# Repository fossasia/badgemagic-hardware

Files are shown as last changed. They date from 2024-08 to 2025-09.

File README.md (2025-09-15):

# Badge Magic Hardware

This repository contains the hardware design files for [Badge Magic](https://badgemagic.fossasia.org), an open-source LED badge platform that lets you create and display custom text, clipart, and animations over Bluetooth using the Badge Magic apps or Python libraries. While its latest hardware revision may not yet be mass-produced, it shares the same RISC-V chip as many other LED badges (e.g., LeSun, Victronics) but provides extra functionality, including a built-in microphone for real-time ambient sound visualization, external flash storage, and two top-mounted buttons that allow for mini-games and other interactive features. To see which functions are supported or in progress, visit the dedicated [firmware repository](https://github.com/fossasia/badgemagic-firmware). 

## PCB Layout

**Front side**

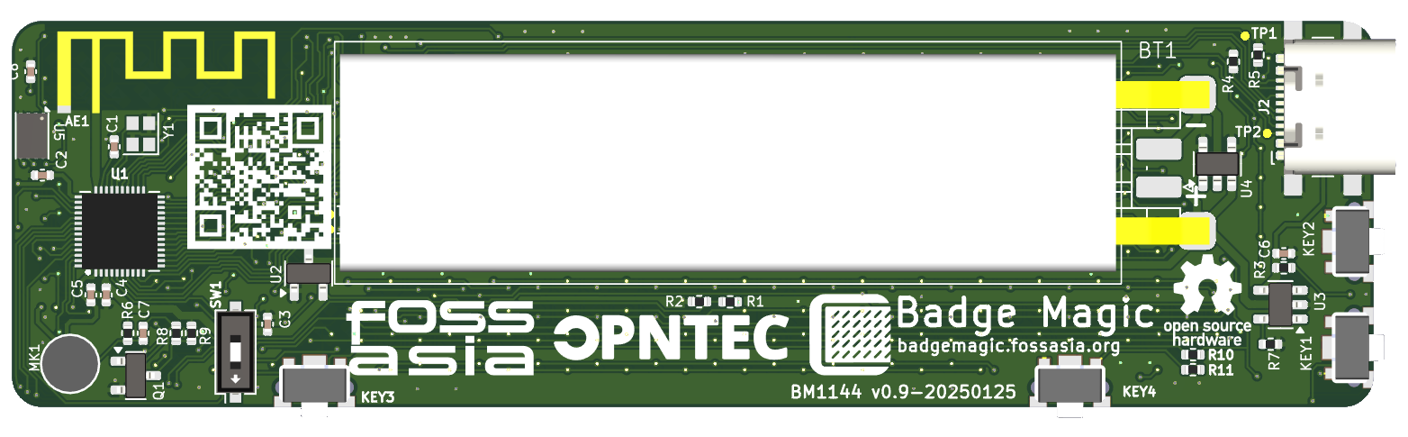
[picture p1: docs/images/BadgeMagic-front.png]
Badge Magic LED front side


**Back side**

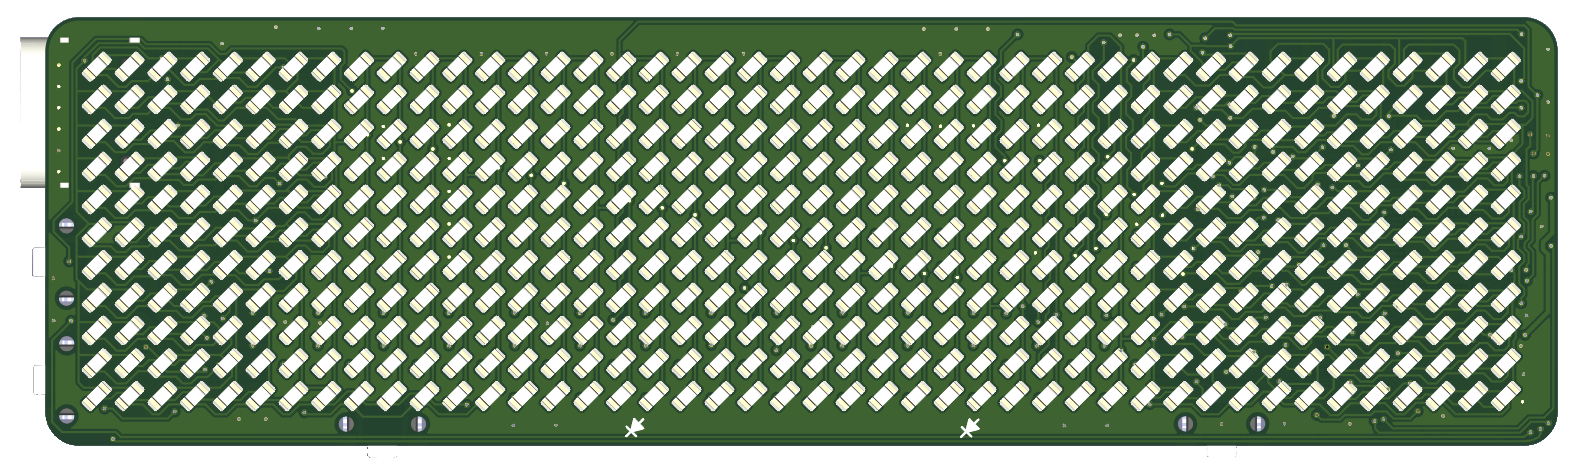
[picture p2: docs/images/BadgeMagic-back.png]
Badge Magic LED back side


## Applications and Firmware Source Repositories

The following software components are available:
* Firmware: https://github.com/fossasia/badgemagic-firmware
* Android app: https://github.com/fossasia/badgemagic-app

## Buy Device

* You can get the board at the [FOSSASIA Shop](https://fossasia.com).

## Platform

* Microcontroller Platform: [WCH QingKe RISC-V Bluetooth](https://wch-ic.com/products/productsCenter/mcuInterface?categoryId=63)
* Toolchain: [MRS_Toolchain_Linux_x64_V1.91](http://www.mounriver.com/download)
* Programming Tool: [wchisp](https://github.com/ch32-rs/wchisp)

## Parts list

- [WCH CH582M(QFN48)](https://www.wch-ic.com/download/file?id=329) Microcontroller
- [XC6206P332MR](https://www.torexsemi.com/file/xc6206/XC6206.pdf)
- [LP4054](https://xor.co.za/post/2022-11-30-hacking-smartwatch/LP4054-Lowpowersemi.pdf) 
- [DW03](https://wmsc.lcsc.com/wmsc/upload/file/pdf/v2/lcsc/2112031830_Shenzhen-Fuman-Elec-DW02R_C2927928.pdf)
- [USB-C](https://www.usb.org/sites/default/files/documents/usb_type-c.zip)
- Electret microphone
- External flash storage
- 32Mhz Crystal
- 3.7v 280mAh Li-ion battery
- LEDs, buttons, resistors, capacitors,
- and [more](docs/bill-of-materials.csv)

## Hardware Specs

- 11x44 LED Matrix display
- BLE 5.3 
- USB 1.1

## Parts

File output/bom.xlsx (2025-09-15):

Comment | Designator | Footprint | JLCPCB Part #
LED | D1,D2,D3,D4,D5,D6,D7,D8,D9,D10,D11,D12,D13,D14,D15,D16,D17,D18,D19,D20,D21,D22,D23,D24,D25,D26,D27,D28,D29,D30,D31,D32,D33,D34,D35,D36,D37,D38,D39,D40,D41,D42,D43,D44,D45,D46,D47,D48,D49,D50,D51,D52,D53,D54,D55,D56,D57,D58,D59,D60,D61,D62,D63,D64,D65,D66,D67,D68,D69,D70,D71,D72,D73,D74,D75,D76,D77,D78,D79,D80,D81,D82,D83,D84,D85,D86,D87,D88,D89,D90,D91,D92,D93,D94,D95,D96,D97,D98,D99,D100 | LED_0603 | C965799
LED | D101,D102,D103,D104,D105,D106,D107,D108,D109,D110,D111,D112,D113,D114,D115,D116,D117,D118,D119,D120,D121,D122,D123,D124,D125,D126,D127,D128,D129,D130,D131,D132,D133,D134,D135,D136,D137,D138,D139,D140,D141,D142,D143,D144,D145,D146,D147,D148,D149,D150,D151,D152,D153,D154,D155,D156,D157,D158,D159,D160,D161,D162,D163,D164,D165,D166,D167,D168,D169,D170,D171,D172,D173,D174,D175,D176,D177,D178,D179,D180,D181,D182,D183,D184,D185,D186,D187,D188,D189,D190,D191,D192,D193,D194,D195,D196,D197,D198,D199,D200 | LED_0603 | C965799
LED | D201,D202,D203,D204,D205,D206,D207,D208,D209,D210,D211,D212,D213,D214,D215,D216,D217,D218,D219,D220,D221,D222,D223,D224,D225,D226,D227,D228,D229,D230,D231,D232,D233,D234,D235,D236,D237,D238,D239,D240,D241,D242,D243,D244,D245,D246,D247,D248,D249,D250,D251,D252,D253,D254,D255,D256,D257,D258,D259,D260,D261,D262,D263,D264,D265,D266,D267,D268,D269,D270,D271,D272,D273,D274,D275,D276,D277,D278,D279,D280,D281,D282,D283,D284,D285,D286,D287,D288,D289,D290,D291,D292,D293,D294,D295,D296,D297,D298,D299,D300 | LED_0603 | C965799
LED | D301,D302,D303,D304,D305,D306,D307,D308,D309,D310,D311,D312,D313,D314,D315,D316,D317,D318,D319,D320,D321,D322,D323,D324,D325,D326,D327,D328,D329,D330,D331,D332,D333,D334,D335,D336,D337,D338,D339,D340,D341,D342,D343,D344,D345,D346,D347,D348,D349,D350,D351,D352,D353,D354,D355,D356,D357,D358,D359,D360,D361,D362,D363,D364,D365,D366,D367,D368,D369,D370,D371,D372,D373,D374,D375,D376,D377,D378,D379,D380,D381,D382,D383,D384,D385,D386,D387,D388,D389,D390,D391,D392,D393,D394,D395,D396,D397,D398,D399,D400 | LED_0603 | C965799
LED | D401,D402,D403,D404,D405,D406,D407,D408,D409,D410,D411,D412,D413,D414,D415,D416,D417,D418,D419,D420,D421,D422,D423,D424,D425,D426,D427,D428,D429,D430,D431,D432,D433,D434,D435,D436,D437,D438,D439,D440,D441,D442,D443,D444,D445,D446,D447,D448,D449,D450,D451,D452,D453,D454,D455,D456,D457,D458,D459,D460,D461,D462,D463,D464,D465,D466,D467,D468,D469,D470,D471,D472,D473,D474,D475,D476,D477,D478,D479,D480,D481,D482,D483,D484 | LED_0603 | C965799
Conn_01x02 | J1 | JST_1x02_P2.50mm_SMD_Horizontal | C7429680
CH582M | U1 | CH582-QFN-48-1EP_5x5mm_P0.35mm_EP3.7x3.7mm | C2920766
MMBT3904 | Q1 | SOT-23 | C20526
3k92 | R7 | 0402 | C137988
47k | R8 | 0402 | C25792
button | KEY1,KEY2,KEY3,KEY4 | 1TS003A-1800-3500A-CT | C255805
DW03 | U4 | SOT-23-5 | C5122490
USB_C_Receptacle_USB2.0_16P | J2 | USB_C_Receptacle_GCT_USB4110 | C963216
MIC-4013-G-G00 | MK1 | microphone | C42371093
NORFlash | U5 | USON-8_2x3 | C7462744
2.2uF | C1,C2,C3,C4,C5,C6,C7,C8 | 0402 | C12530
100k | R2 | 0402 | C60491
4.7k | R6,R9 | 0402 | C25940
XC6206P362MR | U2 | SOT-23-3 | C351446
LP4054 | U3 | SOT-23-5 | C517187
32MHz | Y1 | Crystal_SMD_2016-4Pin_2.0x1.6mm | C2901738
30K | R3 | 0402 | C25776
5.1k | R4,R5 | 0402 | C25941
1k | R10,R11 | 0402 | C2906899
182k | R1 | 0402 | C5159679
SW_DIP_x01 | SW1 | SW_DIP_SPSTx01_Slide_Copal_CHS-01TA_W5.08mm_P1.27mm_Jpin | C2921603

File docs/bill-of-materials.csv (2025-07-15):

Reference | Value | Datasheet | Footprint | Qty
BT1 | 3.7v 280mAh | ~ | BadgeMagic:Battery cell | 1
C1,C2,C3,C4,C5,C6,C7,C8 | 2.2uF | ~ | Capacitor_SMD:C_0402_1005Metric | 8
D1,D2,D3,D4,D5,D6,D7,D8,D9,D10,D11,D12,D13,D14,D15,D16,D17,D18,D19,D20,D21,D22,D23,D24,D25,D26,D27,D28,D29,D30,D31,D32,D33,D34,D35,D36,D37,D38,D39,D40,D41,D42,D43,D44,D45,D46,D47,D48,D49,D50,D51,D52,D53,D54,D55,D56,D57,D58,D59,D60,D61,D62,D63,D64,D65,D66,D67,D68,D69,D70,D71,D72,D73,D74,D75,D76,D77,D78,D79,D80,D81,D82,D83,D84,D85,D86,D87,D88,D89,D90,D91,D92,D93,D94,D95,D96,D97,D98,D99,D100,D101,D102,D103,D104,D105,D106,D107,D108,D109,D110,D111,D112,D113,D114,D115,D116,D117,D118,D119,D120,D121,D122,D123,D124,D125,D126,D127,D128,D129,D130,D131,D132,D133,D134,D135,D136,D137,D138,D139,D140,D141,D142,D143,D144,D145,D146,D147,D148,D149,D150,D151,D152,D153,D154,D155,D156,D157,D158,D159,D160,D161,D162,D163,D164,D165,D166,D167,D168,D169,D170,D171,D172,D173,D174,D175,D176,D177,D178,D179,D180,D181,D182,D183,D184,D185,D186,D187,D188,D189,D190,D191,D192,D193,D194,D195,D196,D197,D198,D199,D200,D201,D202,D203,D204,D205,D206,D207,D208,D209,D210,D211,D212,D213,D214,D215,D216,D217,D218,D219,D220,D221,D222,D223,D224,D225,D226,D227,D228,D229,D230,D231,D232,D233,D234,D235,D236,D237,D238,D239,D240,D241,D242,D243,D244,D245,D246,D247,D248,D249,D250,D251,D252,D253,D254,D255,D256,D257,D258,D259,D260,D261,D262,D263,D264,D265,D266,D267,D268,D269,D270,D271,D272,D273,D274,D275,D276,D277,D278,D279,D280,D281,D282,D283,D284,D285,D286,D287,D288,D289,D290,D291,D292,D293,D294,D295,D296,D297,D298,D299,D300,D301,D302,D303,D304,D305,D306,D307,D308,D309,D310,D311,D312,D313,D314,D315,D316,D317,D318,D319,D320,D321,D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 | LED | ~ | BadgeMagic:LED_0603 | 484
J1 | Conn_01x02 | ~ | BadgeMagic:JST_1x02_P2.50mm_SMD_Horizontal | 1
J2 | USB_C_Receptacle_USB2.0_16P | https://www.usb.org/sites/default/files/documents/usb_type-c.zip | BadgeMagic:USB_C_Receptacle_GCT_USB4110 | 1
KEY1,KEY2,KEY3,KEY4 | button | https://www.lcsc.com/product-detail/Tactile-Switches_HYP-Hongyuan-Precision-1TS003A-1800-3500A-CT_C255806.html | BadgeMagic:1TS003A-1800-3500A-CT | 4
MK1 | SAMZO MIC-4013-G-G00 | https://lcsc.com/datasheet/lcsc_datasheet_2410281656_SAMZO-MIC-4013-G-G00_C42371093.pdf | BadgeMagic:microphone | 1
Q1 | MMBT3904 | https://www.onsemi.com/pdf/datasheet/pzt3904-d.pdf | Package_TO_SOT_SMD:SOT-23 | 1
R1 | 182k | ~ | Resistor_SMD:R_0402_1005Metric | 1
R2 | 100k | ~ | Resistor_SMD:R_0402_1005Metric | 1
R3 | 30K | ~ | Resistor_SMD:R_0402_1005Metric | 1
R4,R5 | 5.1k | ~ | Resistor_SMD:R_0402_1005Metric | 2
R6,R9 | 4.7k | ~ | Resistor_SMD:R_0402_1005Metric | 2
R7 | 3k92 | ~ | Resistor_SMD:R_0402_1005Metric | 1
R8 | 47k | ~ | Resistor_SMD:R_0402_1005Metric | 1
R10,R11 | 1k | ~ | Resistor_SMD:R_0402_1005Metric | 2
SW1 | SW_DIP_x01 | ~ | Button_Switch_SMD:SW_DIP_SPSTx01_Slide_Copal_CHS-01A_W5.08mm_P1.27mm_JPin | 1
U1 | CH582M | https://github.com/openwch/ch583/tree/main/Datasheet | BadgeMagic:CH582-QFN-48-1EP_5x5mm_P0.35mm_EP3.7x3.7mm | 1
U2 | XC6206P362MR | https://www.torexsemi.com/file/xc6206/XC6206.pdf | Package_TO_SOT_SMD:SOT-23-3 | 1
U3 | LP4054 | https://xor.co.za/post/2022-11-30-hacking-smartwatch/LP4054-Lowpowersemi.pdf | Package_TO_SOT_SMD:TSOT-23-5 | 1
U4 | DW03 | https://wmsc.lcsc.com/wmsc/upload/file/pdf/v2/lcsc/2112031830_Shenzhen-Fuman-Elec-DW02R_C2927928.pdf | Package_TO_SOT_SMD:SOT-23-5 | 1
U5 | NOR Flash | ~ | BadgeMagic:USON-8_2x3 | 1
Y1 | 32 MHz | ~ | Crystal:Crystal_SMD_2016-4Pin_2.0x1.6mm | 1

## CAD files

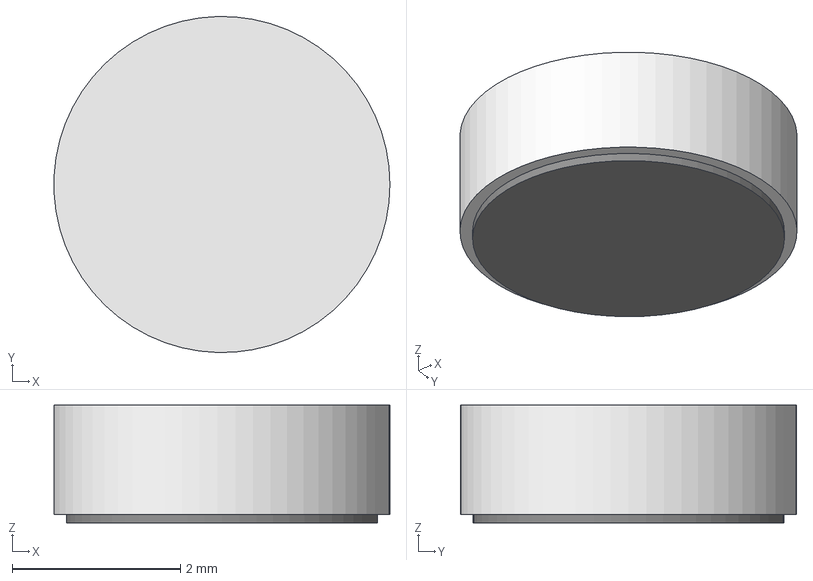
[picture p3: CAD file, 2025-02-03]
schematics/3dmodels/microphone.step
4.00 x 4.00 x 1.40 mm

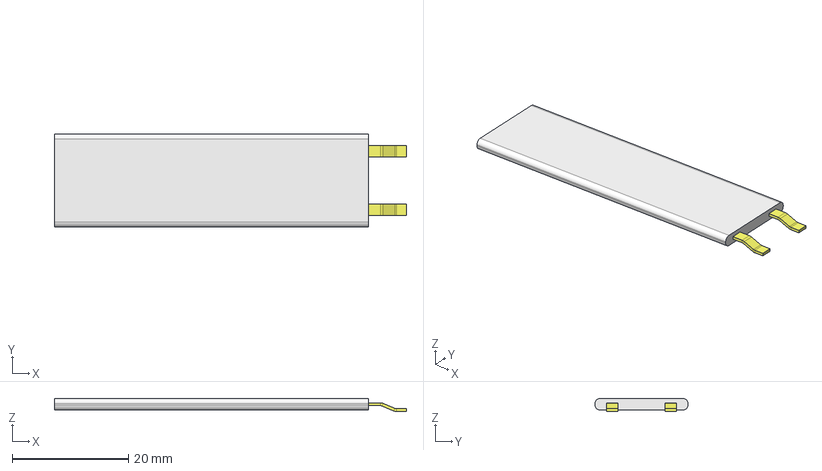
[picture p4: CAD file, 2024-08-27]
schematics/3dmodels/batt.step
60.5 x 16.0 x 2.25 mm
electro1
electro2

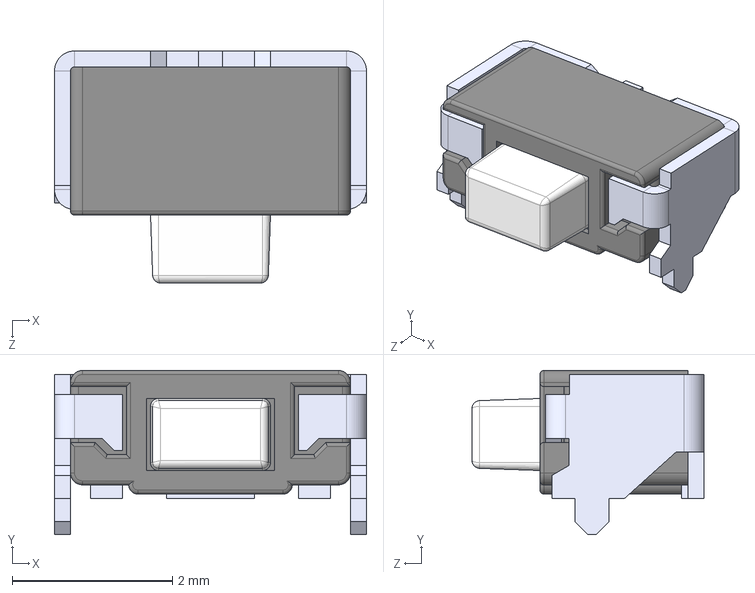
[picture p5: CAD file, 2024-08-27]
schematics/3dmodels/1TS003A-1800-3500A-CT.step
3.90 x 2.05 x 2.90 mm

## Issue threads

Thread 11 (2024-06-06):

Mismatch PCB / Schematic

simon-budig, 2024-06-06:
When looking at the PCB of my (violet) badge I've noticed that there is a mismatch between the PCB and the kicad schematics.

For me the silkscreen on the PCB shows the markings "KEY1" "IC1" and "C3". It seems that they refer to the three parts (button, voltage regulator, capacitor) to the left of them.

The schematics refer to the voltage regulator as "U2", I suspect this could be changed to "IC1" to match up the labels.

Also, the voltage regulator on my board is marked "665k", which refers to the 3.6V-version of the XC6206 (which also matches the measured voltage on my badge). If that part is the same for the other colors of the badge (not sure about that, different color LEDs might need slightly different voltages) the part number in the schematics could be adjusted to "XC6206P362MR".

kienvo, 2024-06-09:
Sorry for being late. I forgot to turn on notification for this repo.

For the IC ref, not just IC1 was mismatched but all four ICs. Two of them were missed ref. The two others were "IC1" and "U1", but they don't match up. IMO, ICs shouldn't have two different ref notations in the same schematic, so they were intentionally annotated from left to right. We could drop a short note near the regulator symbol to indicate this is "IC1" on the original PCB, and so the charger.

About the regulator, I've just checked on red, yellow, and green; they are the same "665k". It was my mistake, didn't notice the part number while pulling it out from built-in symbol.

Closed 2024-08-11.

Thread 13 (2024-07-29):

Design a new board

kienvo, 2024-07-29:
For now, we have just a schematic for firmware reference. We will need a new PCB with more features added, easier debugging, and better design.

Closed 2024-08-27.

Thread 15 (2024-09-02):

Unconnected LEDs

kienvo, 2024-09-02:
Half of the LEDs (pins in the green rectangle below) are mistakenly left unconnected in the schematic.

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

Closed 2024-09-08.

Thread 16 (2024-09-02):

PCB dimensions are incompatible with other versions

kienvo, 2024-09-02:
The current board is slightly bigger than the other versions, making it difficult to interchange with the same casing.

Closed 2024-09-08.

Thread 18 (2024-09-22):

Add a mechanical switch to disable microphone - most hackers hate microphones without hardware switches

froscon2024, 2024-09-22:
The badge is been sold often at hackerspace-minded people. The upcomming USB-C version have a microphone build in: https://github.com/fossasia/badgemagic-hardware/pull/14#issuecomment-2297284782
Could you please add a hardware switch that can turn on and off the microphone? There would be for sure many hackers that would not like to have a microphone the can not turn off.

I would let a picture of the PinePhone (Pro) with its dip-switches that can fully disable microphone here for inspiration.
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

Closed 2024-11-03.

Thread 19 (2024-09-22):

Make the battery detachable without the need of soldering - have to be detached to update firmware at the moment

froscon2024, 2024-09-22:
At the moment the battery have to be detached to update firmware.
https://github.com/fossasia/badgemagic-firmware/issues/38
Having to apply high temperature at the contacts of a lithium battery to install FOSS-firmware is really not great. Please make the battery detachable with a typical connector. This would also make it more user friendly to replace or upgrade the battery. Soldered in batteries are in general not great and if the badge would at some time be reviewed by ifixit it would get negative points for the soldered in battery. There are a ton of cheap, simple and flat connectors you can use instead.

kienvo, 2024-09-23:
Not sure how ifixit will rate a 2-pos DIP switch for both this and #18 :D

froscon2024, 2024-09-25:
I was more thinking of a connector for the battery. Not a DIP switch. Ifixit love of course not soldered in batteries. You can disconnect the battery thanks to the connector to flash but also to hack around with the badge. When you for example need for a special use case where the badge should run a week untouched, then disconnect the internal battery, leave the back off and connect with the same connector type some different battery. For example a 5000mAh 21700 battery cell.
Typical connectors hardware hackers and hackerspaces have around are the ones from the CR2032 batteries used in thinkpads. The connector is small, should fit inside the badge without problems and hardware hackers can already have some of them around.
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

Closed 2024-11-03.

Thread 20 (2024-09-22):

CH583, CH582M or CH582 build in? lsusb reports CH583

froscon2024, 2024-09-22:
What chipset is build into the hardware revision @mariobehling brought to froscon 2024? In lsusb/dmesg it reports with the preinstalled firmware to be a CH583.
The parts list is telling to be a CH582M https://github.com/fossasia/badgemagic-hardware?tab=readme-ov-file#parts-list
The firmware page is telling to be a CH582 https://github.com/fossasia/badgemagic-firmware?tab=readme-ov-file#chipset

kienvo, 2024-09-23:
CH583 is CH583M for short =], the same for CH582. Comparison table from the datasheet:
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

CH582 and CH583 are almost identical. The difference is the CH583 has an additional SPI and 1.7v min. supply voltage. In most cases, they can be interchangeable.

froscon2024, 2024-09-23:
Thanks for the information.
What does your preinstalled OEM closed source firmware say about the build in chipset in lsusb?

kienvo, 2024-09-23:
Both my USB-C version and Micro-USB version, lsusb said 'CH583', but the chip is CH582.

froscon2024, 2024-09-25:
I flashed some hours ago on all badges i have the foss firmware. I checked on the chip and it was always WCH labeled CH582M.

Closed 2024-09-25.

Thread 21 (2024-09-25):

Do not use the suppier of the yellow badges any more - bad build quality, a not working LED and missing part on PCB

froscon2024, 2024-09-25:
I have badges with different colors from Froscon2024. The yellow one looks really bad. One of the LED's simply just do not work. I opened it to flash the new FOSS firmware and compared to other ones its really bad overall. Even the used solderpaste they used to solder on the battery is the really worse one. The one that leave behind not a shiny surface but a milky mess. Even after i heated it up twice (disconnect and connect of battery to flash firmware) the solder stayed like that. I know this type of solder and its always used on really, really crappy products.
The PCB also miss a part that is not missing on the other ones. Its the SMD part directly next to "R3" that is on the bottom of the PCB next to the battery.
And the worst part is one of the yellow LED's is not working in the middle of the badge. It does not matter if closed source firmware or the new released opensource one. It always stay dark, break the letters i try to write and just look bad.
The PCB number of the yellow badge is B1144_220515. Its also missing the production date the other have on the top right next to the PCB number.

mariobehling, 2025-01-09:
Hi @froscon2024 we are still looking at options for future production batches. Even though it is already some time ago, could you take maybe a picture of the issue with the yellow LED?

froscon2024, 2025-08-25:
I think this is solved now. The badge with this production issues have been shown and discussed in person to @mariobehling

Closed 2025-08-25.

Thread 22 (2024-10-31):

Case compatibility

kienvo, 2024-10-31:
The current PCB has battery position that won't fit into the case.

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

Closed 2024-10-31.

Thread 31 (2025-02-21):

Correcting the debug port

kienvo, 2025-02-21:
I was experimenting with the debug port and confirmed that the debug port is working on PB14/PB15, not PB16/PB17 like the OEM boards.

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

Closed 2025-04-07.

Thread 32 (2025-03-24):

Context of the board with other fossasia badges

chrysn, 2025-03-24:
Great to see a Open Hardware badge being developed in this form!

The current README is a bit confusing when coming to this as a user of existing badges that were resold from [LeSun Electronics B1144](https://lesun-led.en.alibaba.com/) -- it easily becomes unclear which hardware one has at hand, and which firmware might work for it.

Could you add some information to the README on how this relates to other boards, and which level of compatibility does it aim for (apparently it aims for display compatibliity with the 11x44 LEDs, but is pin compatibility a goal too?), and what its relation their relation is?

mariobehling, 2025-03-25:
Ok, thanks for question! I think this question is even more relevant for the firmware repo. So, I am moving it there.

To clarify in this repo regarding the hardware, I added the following text into the readme intro already:

While its latest hardware revision may not yet be mass-produced, it shares the same RISC-V chip as many other LED badges (e.g., LeSun, Victronics) but provides extra functionality, including a built-in microphone for real-time ambient sound visualization, external flash storage, and two top-mounted buttons that allow for mini-games and other interactive features. To see which functions are supported or in progress, visit the dedicated [firmware repository](https://github.com/fossasia/badgemagic-firmware).

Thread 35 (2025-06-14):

Badge case doesn't fit after attaching battery connector

hpdang, 2025-06-14:
Once the battery connector (ZX-XH2.54-2PLT) is attached to the LED badge, the existing case no longer fits properly.

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

froscon2024, 2025-08-30:
@mariobehling @hpdang @kienvo
The connector that got installed on there is a complete misunderstanding and that is why it does not fit like written in this issue. Also the huge connector is missing the essential pads left and right for stability on the PCB. The first time the user would have connected or disconnected the battery, the pads would have been ripped off the PCB.

The history of the battery connector for the badge is here: https://github.com/fossasia/badgemagic-hardware/issues/19

I wrote there:
> Typical connectors hardware hackers and hackerspaces have around are the ones from the CR2032 batteries used in thinkpads. The connector is small, should fit inside the badge without problems and hardware hackers can already have some of them around.

Short after the text i wrote it got closed as completed and i expected to have helped with the hardware design to solve the battery disconnect and reconnect issue for flashing and crashed badges. Also for making it possible to replace the battery for a bigger one on the fly, or just easy replace a battery that is worn out after for example 10 years.
A soldered in battery is also bad for repair score at https://www.ifixit.com/ and just bad in general. That is why every good device these days is using a connector to connect a battery and not solder.

When i was sitting at froscon2025 next to @mariobehling holding the prototype PCB in my hand i was fully surprised to see a completely different connector on there that obviously does not fit like shown in the first post here.
I opened yewtu.be while sitting next to @mariobehling and showred one of the many videos you can find that show the connector i described. Some example videos:
https://yewtu.be/watch?v=CJtH5S7RURo&t=3m11s
https://yewtu.be/watch?v=VDBTvgQPmls&t=2m28s
https://yewtu.be/watch?v=mV4HNVSFeqg&t=3m15s

The connector is really common. For example also used on this LoRA board for battery connection: https://lilygo.cc/products/lora3

Its the classical connector hardware hackers have around from old/broken notebooks for many, many years.

I soldered out one of those from a broken notebook to completely make sure i do not get misunderstood again:

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

I was really not expecting to be misunderstood that bad. So let me write more about how to design that part:
I know that having more layers is costly. That is where the connector also benefits. Because the metal left and right next to the connector does not have any electrical connection (like for example the housing of a usb-c SMD connector).
That is why you could for example just leave two holes in the coating and then the connector would be soldered its left and right stability marts on to two led pins. Yes, the voltage from those two LED pins would also be on the left and right side of the battery connector, but that should not matter, because from the electrical point of view those are isolated.
You can also move the connector around in the PCB design. The connector does not have to be in the middle where the battery was soldered before. Because thanks to connecting the battery with a short wire, the placing of the connector is flexible now.
But do not forget the pads left and right that protects the connector from getting ripped from the PCB when connecting and disconnecting the battery. Those are the pads that hold the battery connector in place. Not the two electric relevant pads on the back that connect the battery.
I am telling this especially because those two pads left and right next to the connector was also required for the huge wrong connector but is also missing on there.

From DIY-perspective the correct connector you can see on the last picture have been glued down to not pull/push on the pins on the back and because the essential pads was missing.
You can see in the picture where both, the wrong huge and the correct small are upside down next to each other with white background. Both connectors have those isolated stability pads left and right next to them.

In the last picture you can see that the correct connector is smaller then the USB-C connector and would fit without any issues in the case.

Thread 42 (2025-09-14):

Discussion: Update to the newer CH585M/585M, also now more options to reduce to smaller chip size

froscon2024, 2025-09-14:
There is the now the new chipset released by WCH. I checked the QFN48 version and its pin compatible to my understanding with the CH582M QFN48 that is used now.

Datasheet of CH583/582: https://www.wch-ic.com/download/file?id=329
Datasheet of CH585/584: https://www.wch-ic.com/download/file?id=402

Compare: https://wch-ic.com/products/productsCenter/mcuInterface?categoryId=63

The CH585 have higher speed then the current CH582. This should have general benefits for example when developing games. Also things like sound processing from the microphone and so on could benefit from the higher clock speed.
The USB speed have been updated. The size of data transferred over USB is not that relevant currently, but maybe it would get later with the flexibility the badgemagic hardware gives.

If chip size matter, there are more options now. Before there was just the the CH582F(QFN28) that was smaller then the QFN48. Now there are many more options. But of course you loose functionality and have PCB design work when you reduce the pin count. So keeping the biggest size (QFN48) would be of course at best when the size of the WCH chip was not a problem.

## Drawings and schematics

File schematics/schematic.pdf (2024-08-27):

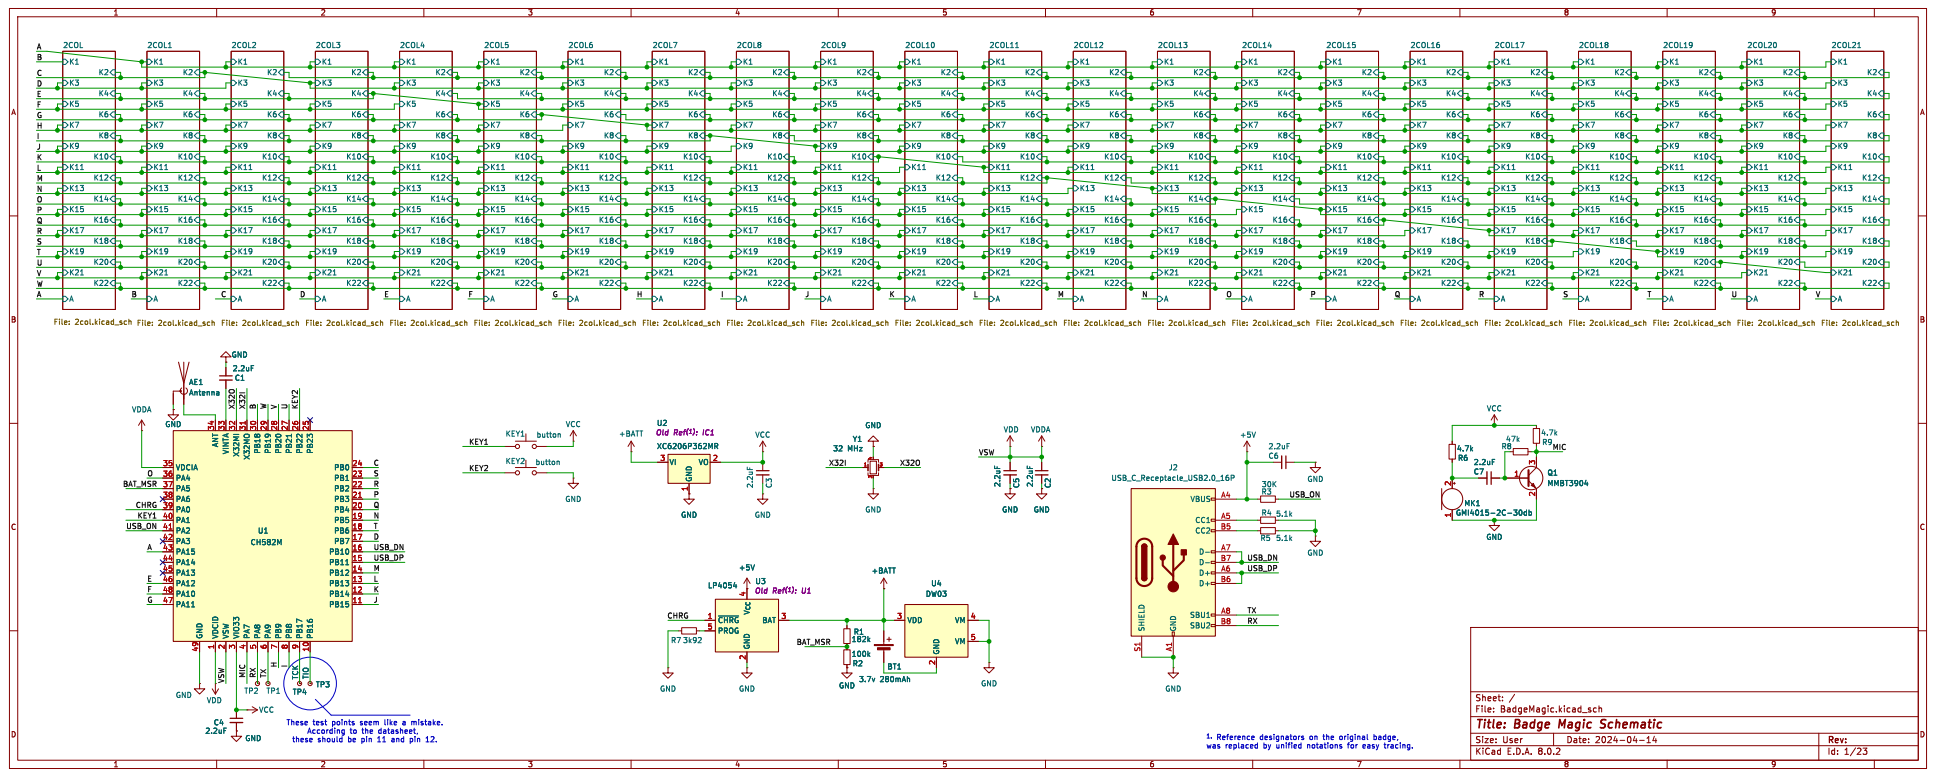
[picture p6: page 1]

1 VO 2 VI 3U2XC6206P362MR Old Ref^{(1)}:IC1 VCC

2 VDD 3 VM 4 VM 5 2.2uF C5 GND 2.2uF C2 GND

2 BAT 3 V_{CC} 4 PROG 5 +5V +BATT R1

2 BAT 3 V_{CC} 4 PROG 5 U3 LP4054 Old Ref^{(1)}:U1 TP4TCK

File: BadgeMagic.kicad_sch Sheet: /
Id: 1/23 Title: Badge Magic Schematic

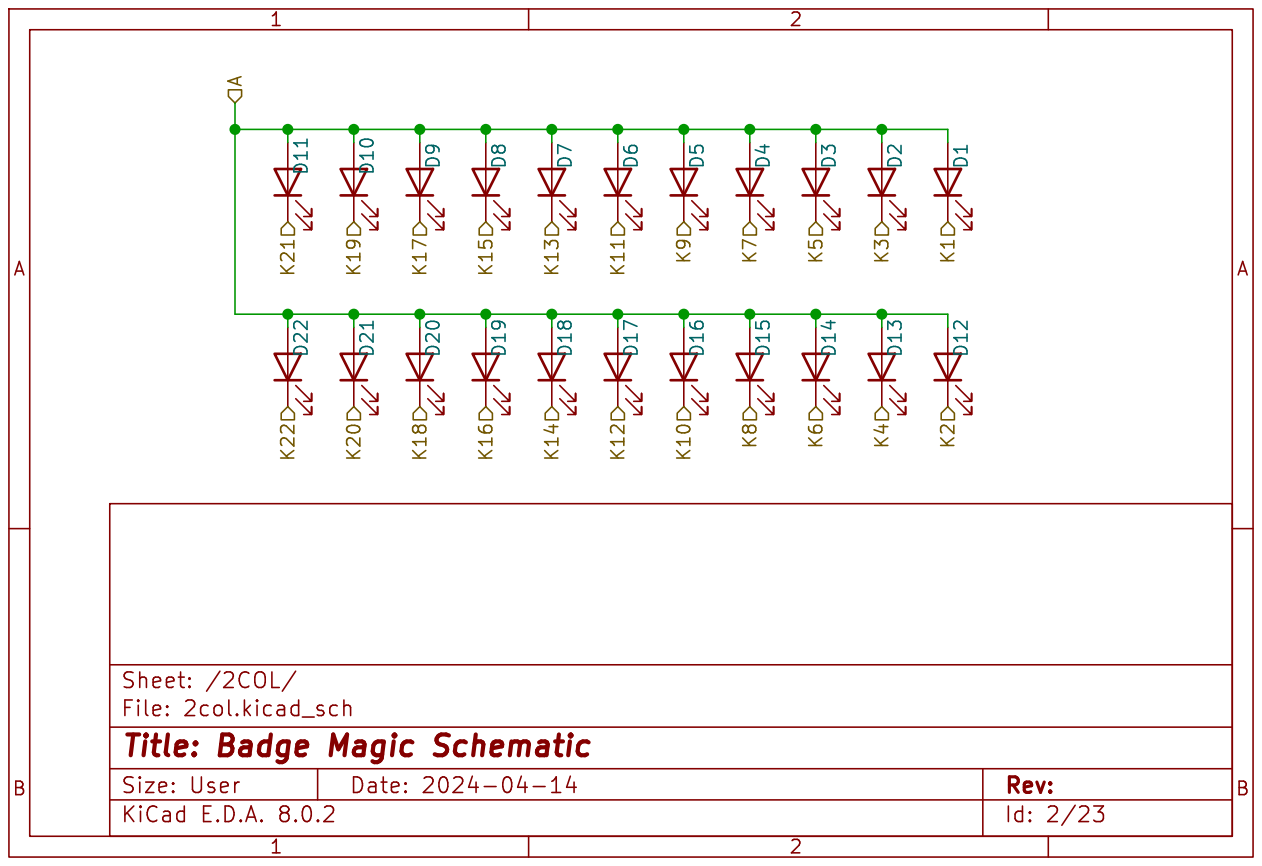
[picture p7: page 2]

Id: 2/23 Title: Badge Magic Schematic

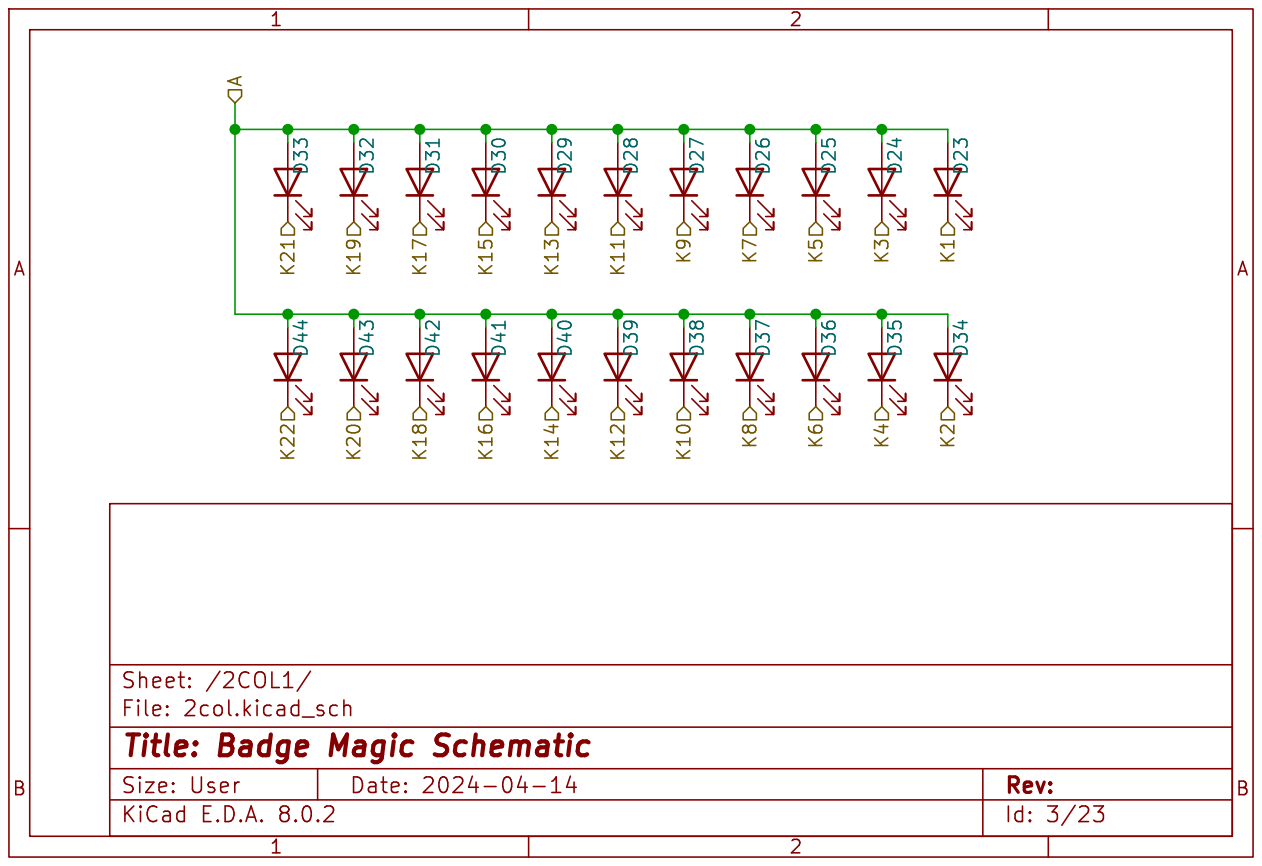
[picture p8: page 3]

Id: 3/23 Title: Badge Magic Schematic

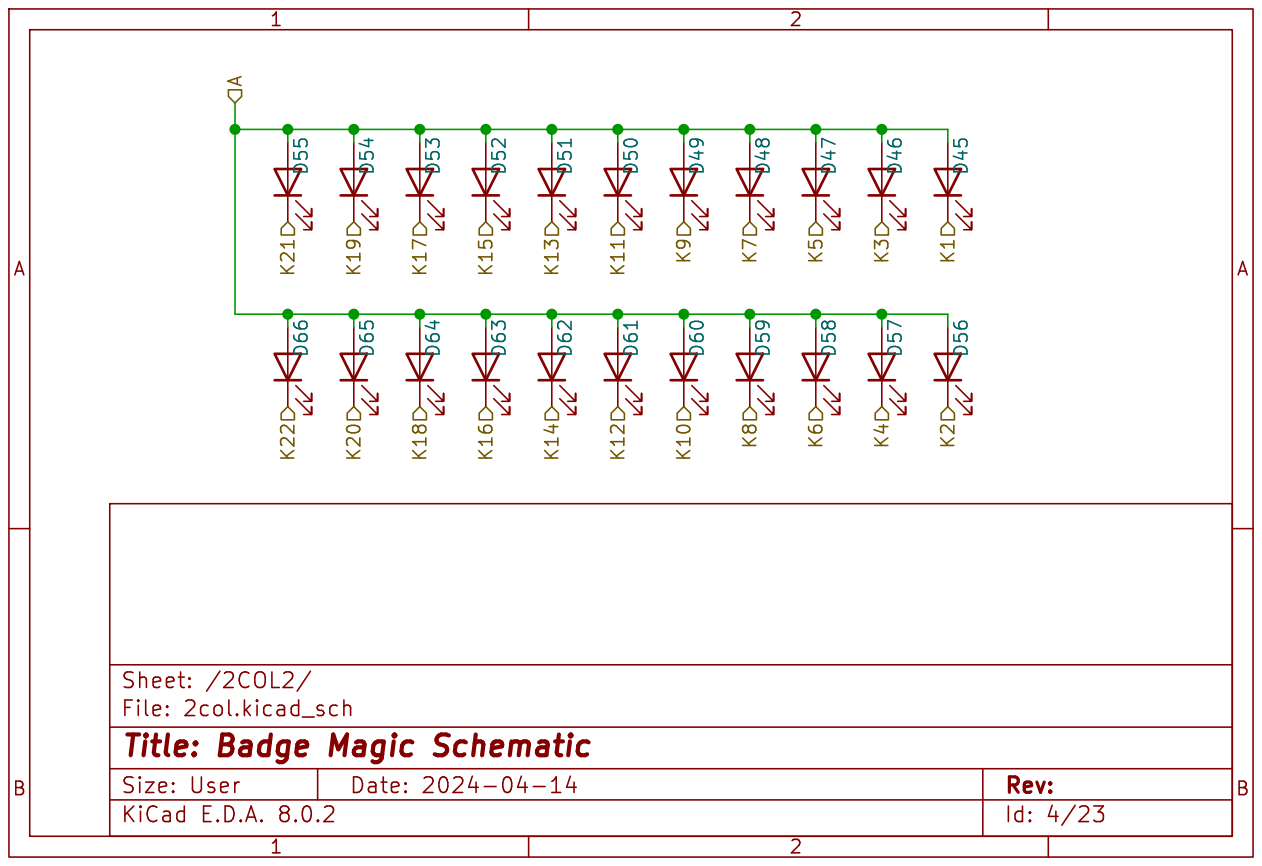
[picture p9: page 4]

Id: 4/23 Title: Badge Magic Schematic

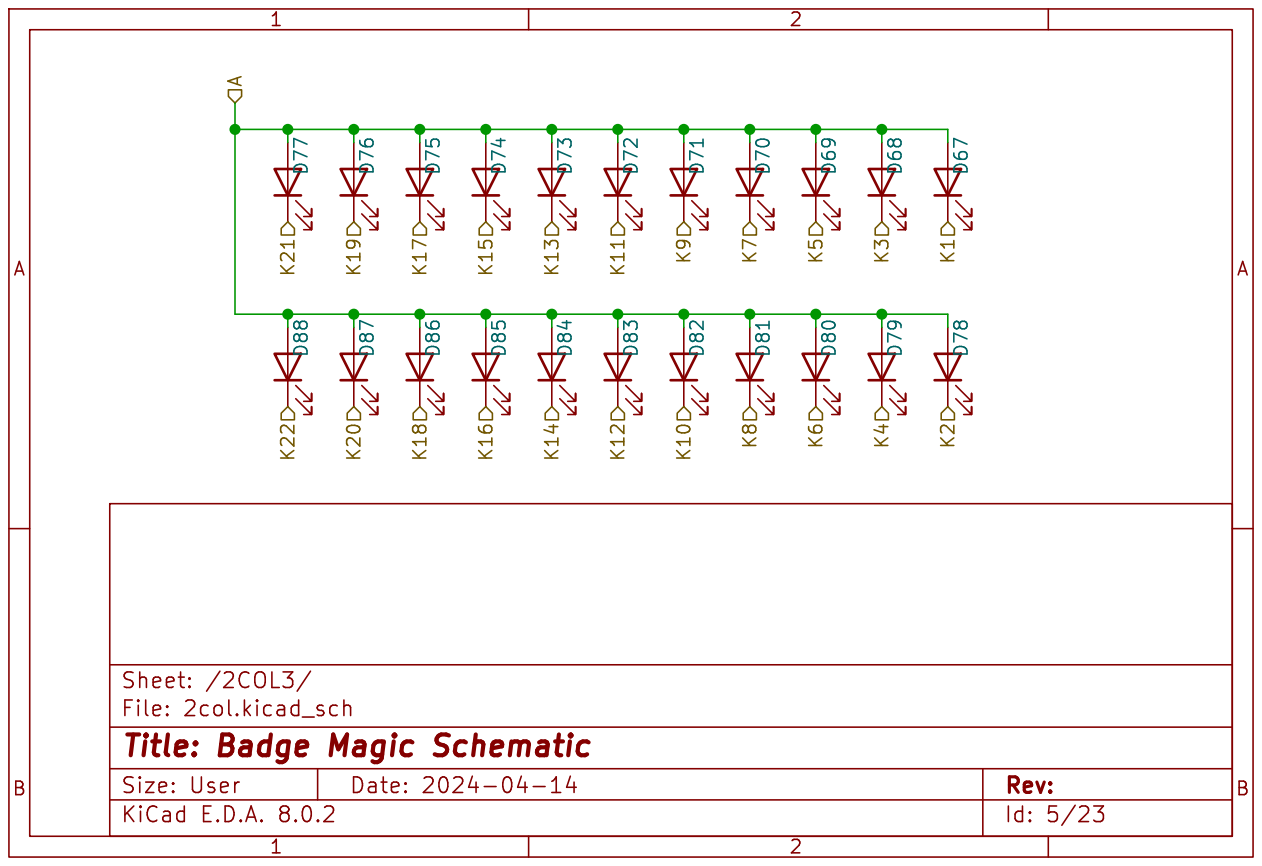
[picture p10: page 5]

Id: 5/23 Title: Badge Magic Schematic

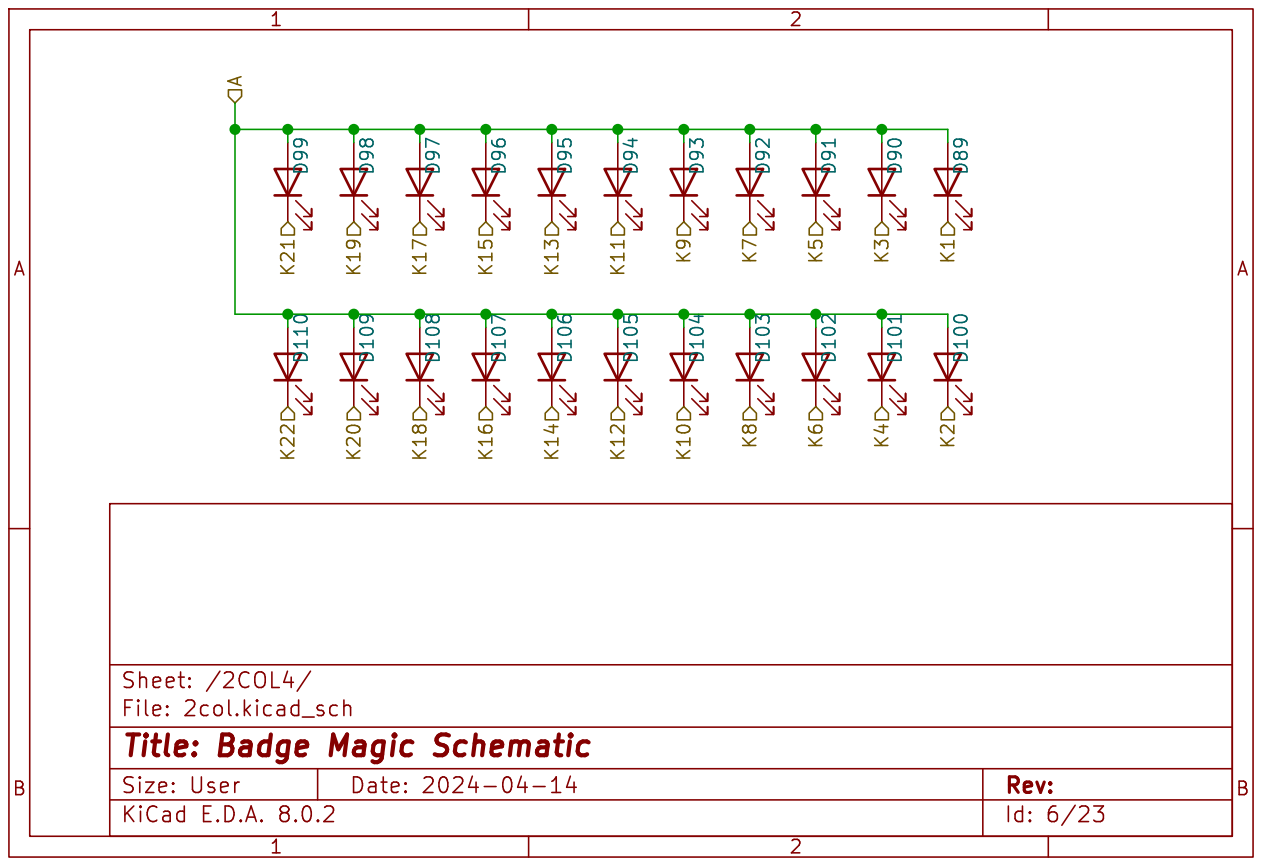
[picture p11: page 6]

Id: 6/23 Title: Badge Magic Schematic

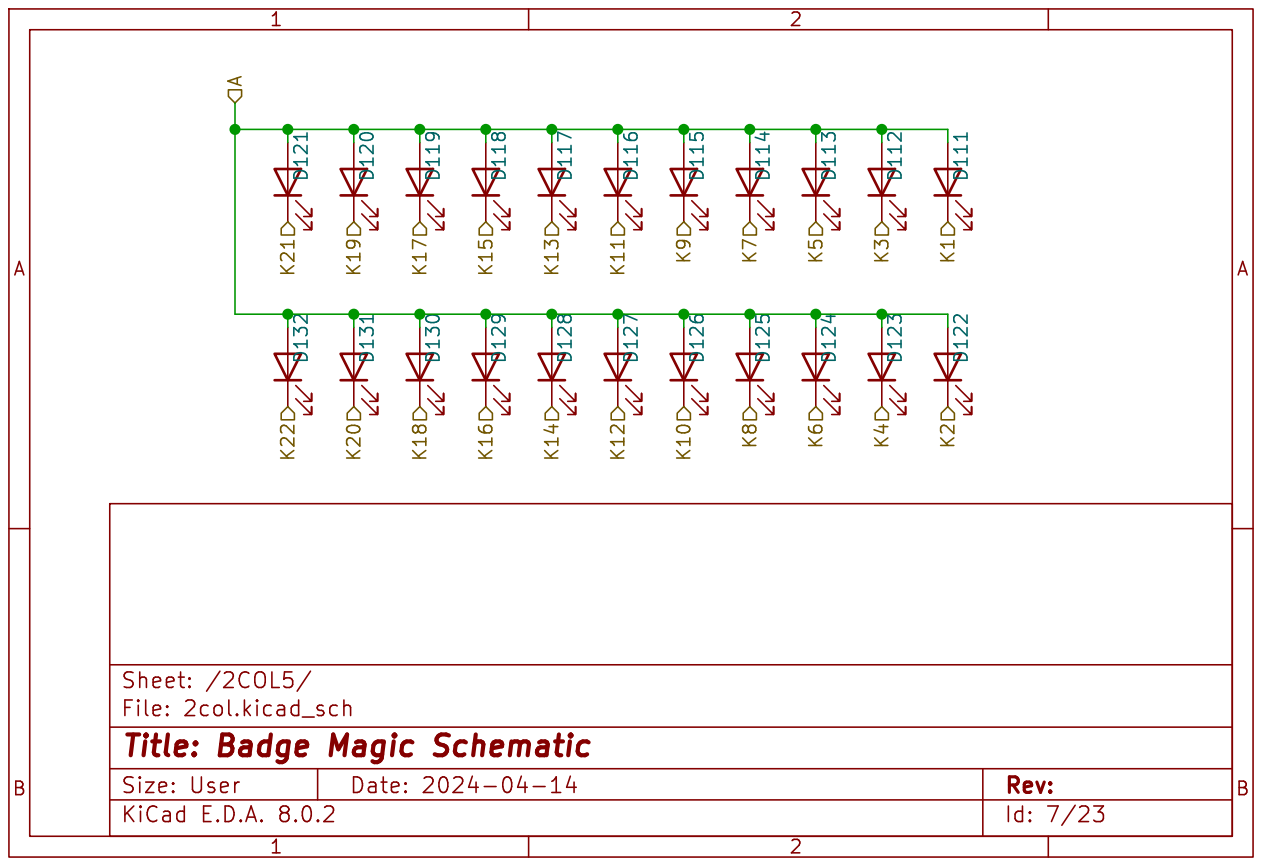
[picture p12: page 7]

Id: 7/23 Title: Badge Magic Schematic

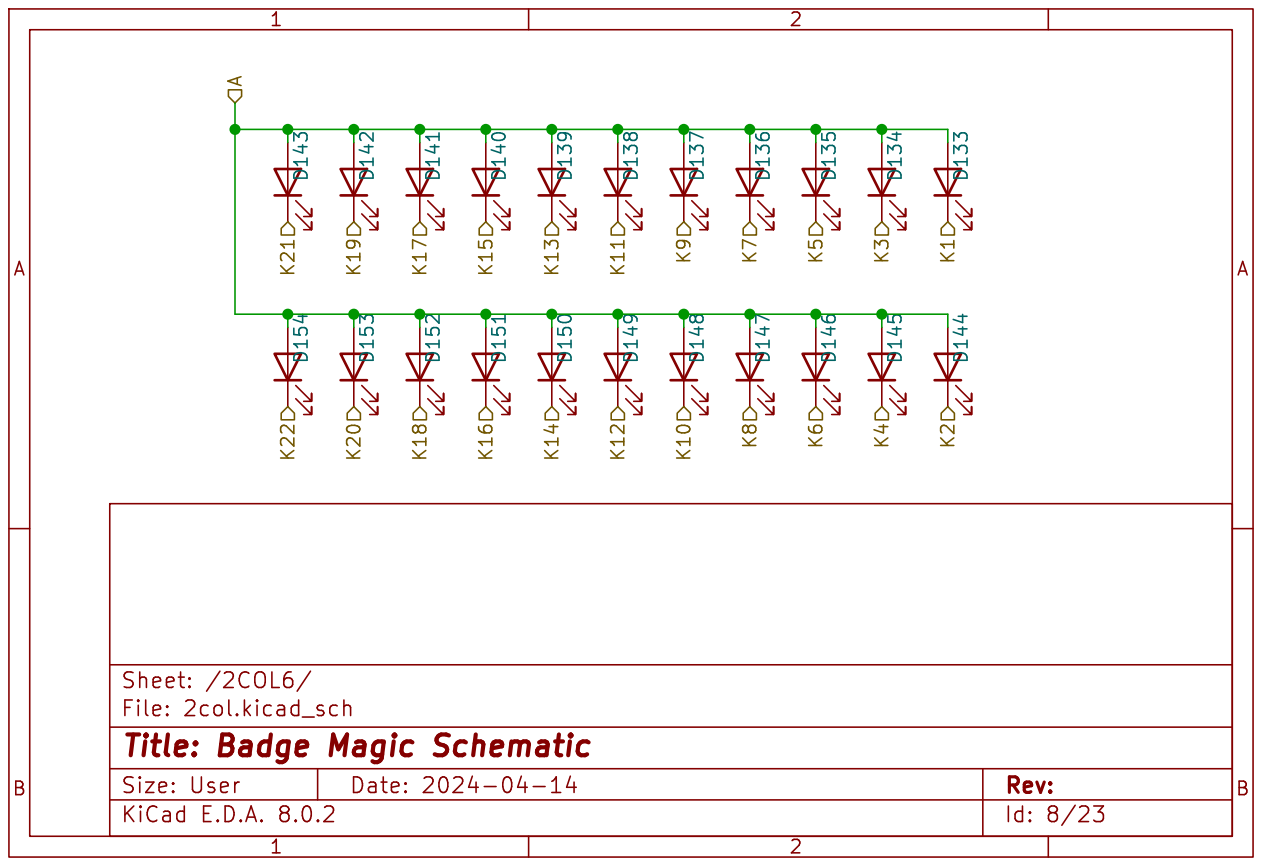
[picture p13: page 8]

Id: 8/23 Title: Badge Magic Schematic

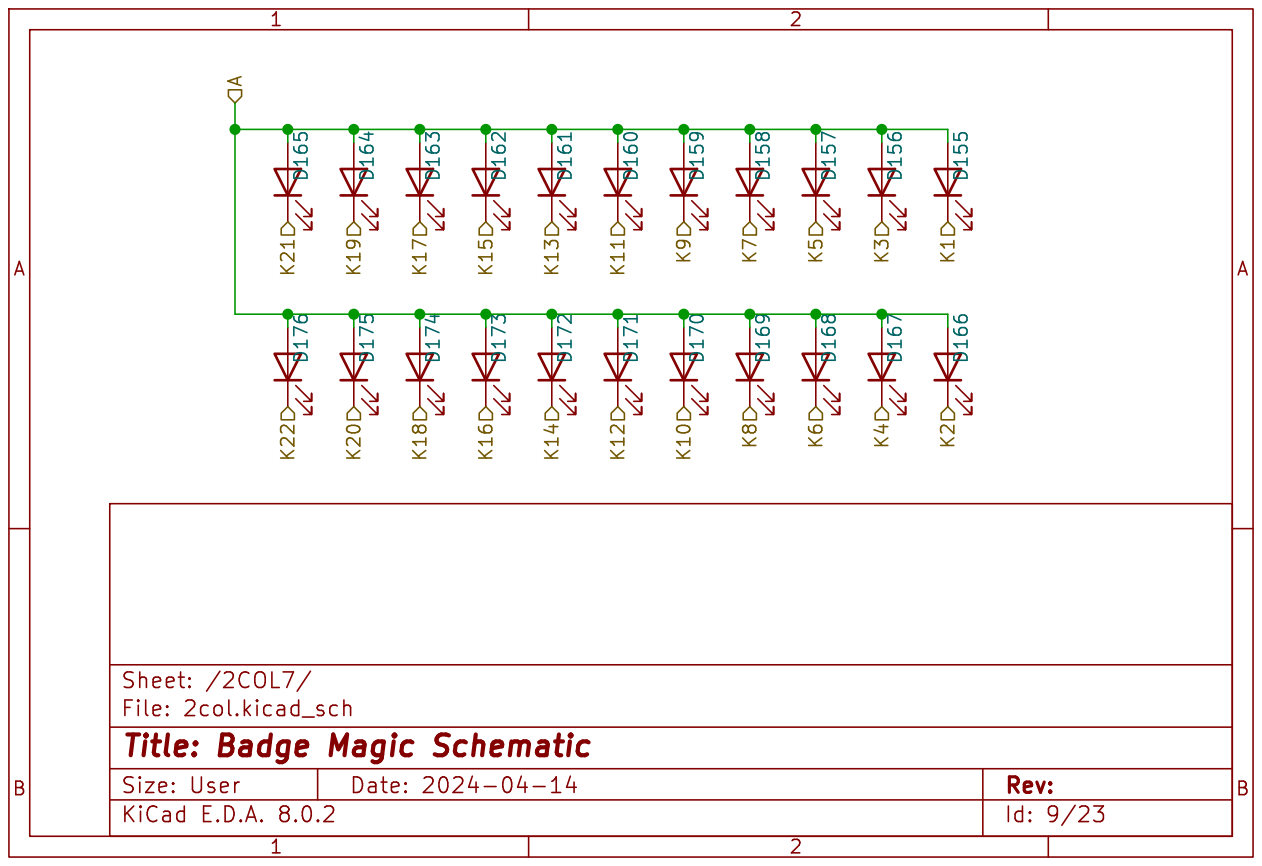
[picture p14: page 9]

Id: 9/23 Title: Badge Magic Schematic

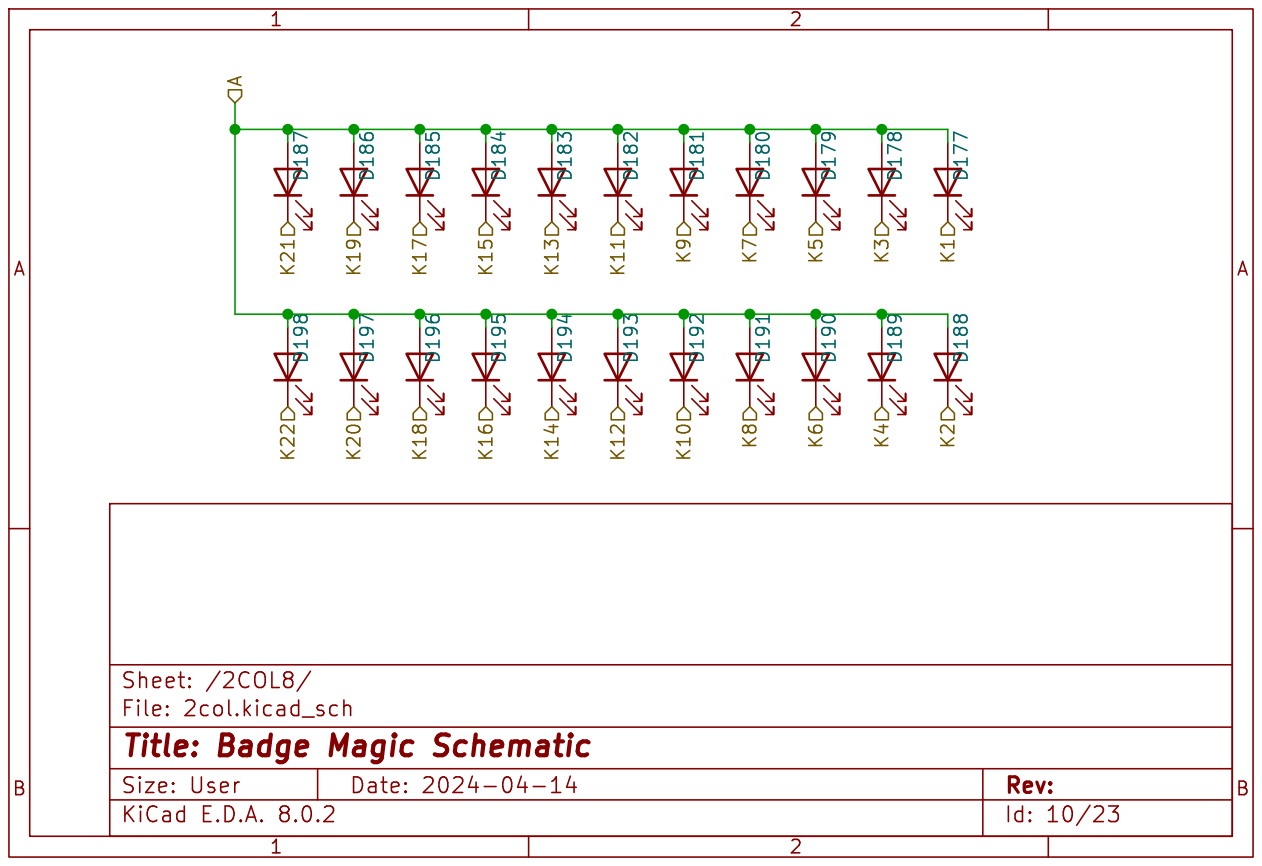
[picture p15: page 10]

Id: 10/23 Title: Badge Magic Schematic

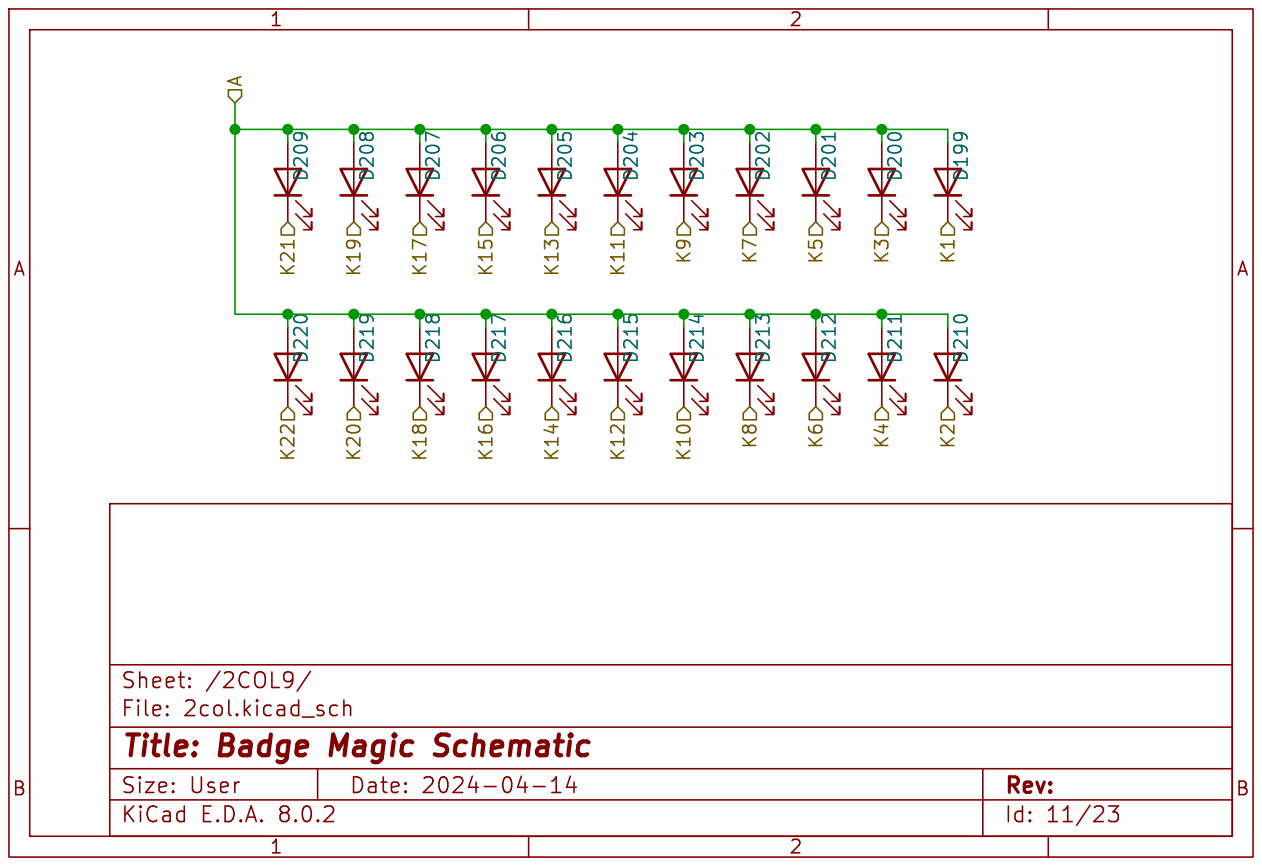
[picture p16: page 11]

Id: 11/23 Title: Badge Magic Schematic

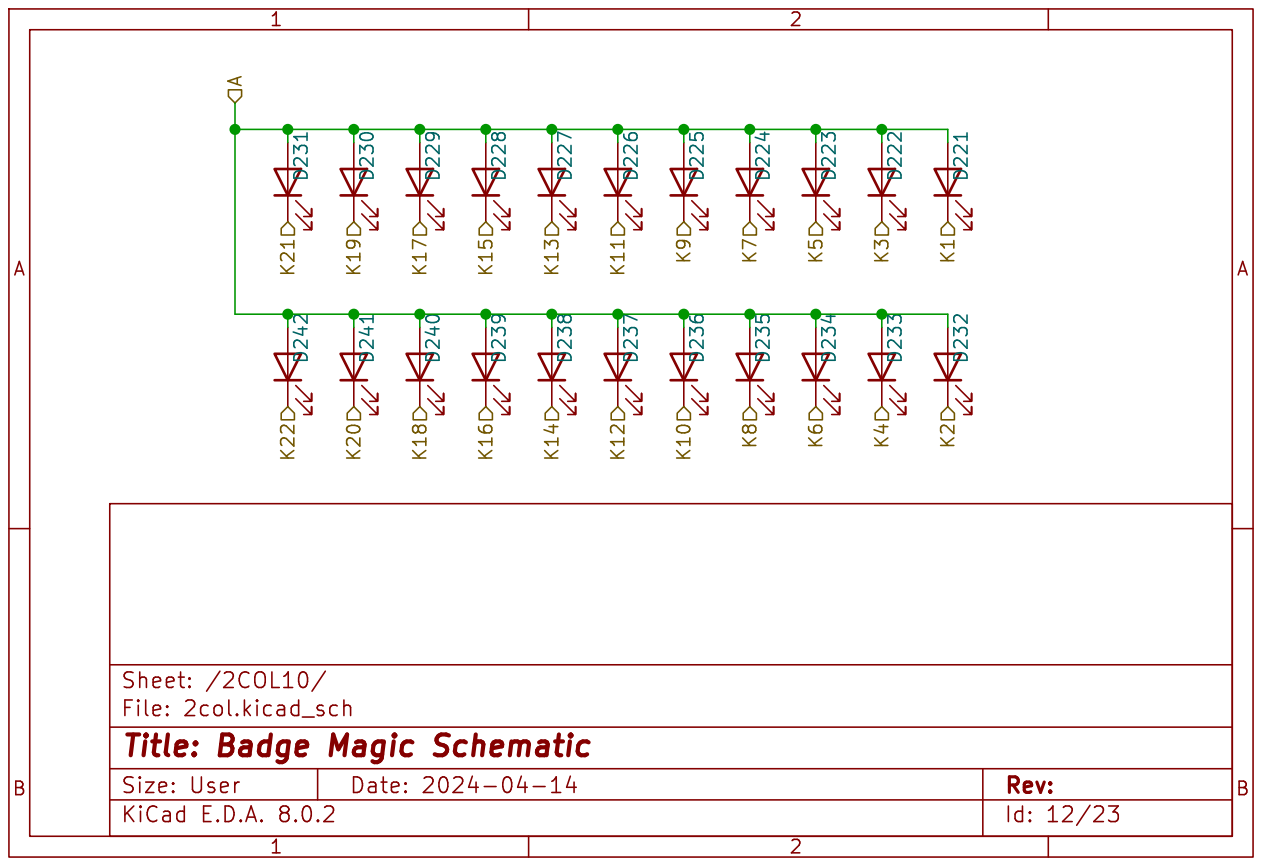
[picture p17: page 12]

Id: 12/23 Title: Badge Magic Schematic


Id: 13/23 Title: Badge Magic Schematic


Id: 14/23 Title: Badge Magic Schematic


Id: 15/23 Title: Badge Magic Schematic


Id: 16/23 Title: Badge Magic Schematic


Id: 17/23 Title: Badge Magic Schematic


Id: 18/23 Title: Badge Magic Schematic


Id: 19/23 Title: Badge Magic Schematic


Id: 20/23 Title: Badge Magic Schematic


Id: 21/23 Title: Badge Magic Schematic


Id: 22/23 Title: Badge Magic Schematic


Id: 23/23 Title: Badge Magic Schematic

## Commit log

2024-05-26 Add KiCad schematics
    [2col.kicad_sch, BadgeMagic.kicad_sch]
2024-05-30 fix: wrong connection
    turn out 2 buttons have different connections
    [BadgeMagic.kicad_sch]
2024-06-12 fix: schematic: mismatch with original pcb
    [BadgeMagic.kicad_sch]
2024-08-27 Badge Magic PCB layout (#14)
    * complete PCB
    * add mic and amplify circuit
    * add 3d models
    * add logos
    * update BOM and schematic pdf
    * update readme with back & front of the PCB layout
    [1TS003A-1800-3500A-CT.step, 2col.kicad_sch, BadgeMagic.kicad_pcb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]
2024-09-08 fix: incompatible dimensions and unconnected leds (#17)
    changes:
    - fix unconnected leds
    - resized led, and CH582 footprints
    - added mounting holes to usb-c receptacle
    - adjusted the spacing of the leds
    - adjusted the board size
    - updated pcb images
    [2col.kicad_sch, BadgeMagic.kicad_pcb, BadgeMagic.kicad_sch]
2024-10-31 fix: battery position for casing compatibility (#23)
    [BadgeMagic.kicad_pcb]
2024-11-03 feat: detachable battery and a switch for microphone (#24)
    [BadgeMagic.kicad_pcb, BadgeMagic.kicad_sch, bill-of-materials.csv]
2025-01-22 fix: button footprint to correct dimensions (#29)
    and also change artworks to graphics instead of footprint
    [BadgeMagic.kicad_pcb]
2025-01-25 add buttons for gaming
    [BadgeMagic.kicad_pcb, BadgeMagic.kicad_sch]
2025-02-01 add spi flash and mic
    [BadgeMagic.kicad_pcb, BadgeMagic.kicad_sch]
2025-02-01 reroute tracks
    [BadgeMagic.kicad_pcb]
2025-02-01 add 3d models for spi flash and mic
    [BadgeMagic.kicad_pcb, BadgeMagic.kicad_sch, microphone-4x2.1.step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]
2025-02-01 update BOM and README
    [2col.kicad_sch, BadgeMagic.kicad_sch, bill-of-materials.csv]
2025-04-07 fix: debug port (#33)
    resolves #31
    [2col.kicad_sch, BadgeMagic.kicad_pcb, BadgeMagic.kicad_sch]
2025-06-13 fix: design rule checks (#34)
    * fix: DRC errors in schematic
    * fix: DRC erros in pcb
    [BadgeMagic.kicad_pcb, BadgeMagic.kicad_sch]
2025-06-24 add gerber file (#37)
    [BadgeMagic-B_Cu.gbr, BadgeMagic-B_Mask.gbr, BadgeMagic-B_Paste.gbr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]
2025-07-11 fix: mic to MIC-4013-G-G00
    [2col.kicad_sch, BadgeMagic.kicad_pcb, BadgeMagic.kicad_sch]
2025-07-11 update bom
    [bill-of-materials.csv]
2025-07-12 update gerber
    [BadgeMagic-B_Cu.gbr, BadgeMagic-B_Mask.gbr, BadgeMagic-B_Paste.gbr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]
2025-07-14 fix pin number
    [BadgeMagic.kicad_pcb, BadgeMagic.kicad_sch]
2025-07-16 increased via pad from 0.4 to 0.45 mm
    [BadgeMagic.kicad_pcb]
2025-07-16 docs: added BoM and CPL files for JLCPCB
    [bom.xlsx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]
2025-09-15 fix: updated part number for SW1 (#40)
    [bom.xlsx]
2026-07-06 Adjust AUX_BTNS resistor divider circuit to support all 4 combinations of button presses (#45)
    * Changed the AUX_BTN resistor divider circuit so that we can distinct voltage readings for all 4 possible combinations of button presses
    * Delete schematics/DRC.rpt
